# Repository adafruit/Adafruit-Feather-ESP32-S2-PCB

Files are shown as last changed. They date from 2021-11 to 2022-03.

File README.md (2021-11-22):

## Adafruit ESP32-S2 Feather

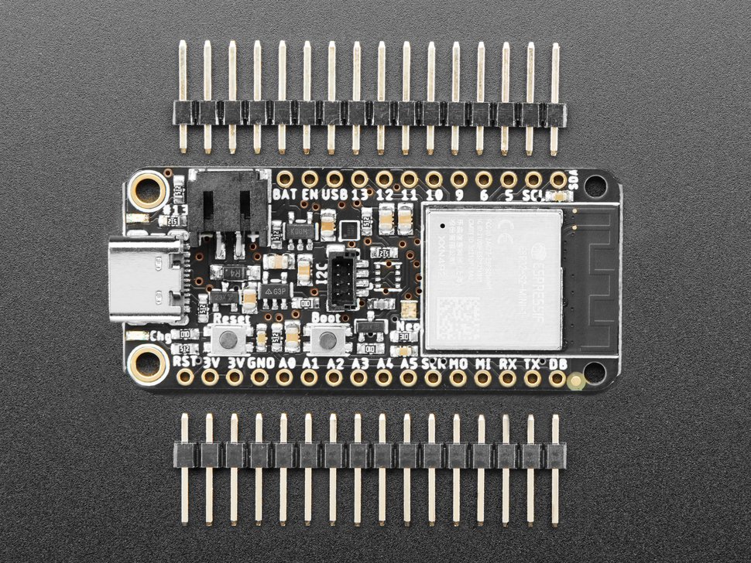
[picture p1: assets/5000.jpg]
<a href="http://www.adafruit.com/products/5000"><br/>
Click here to purchase one from the Adafruit shop</a>

### ESP32-S2 Feather with BME280

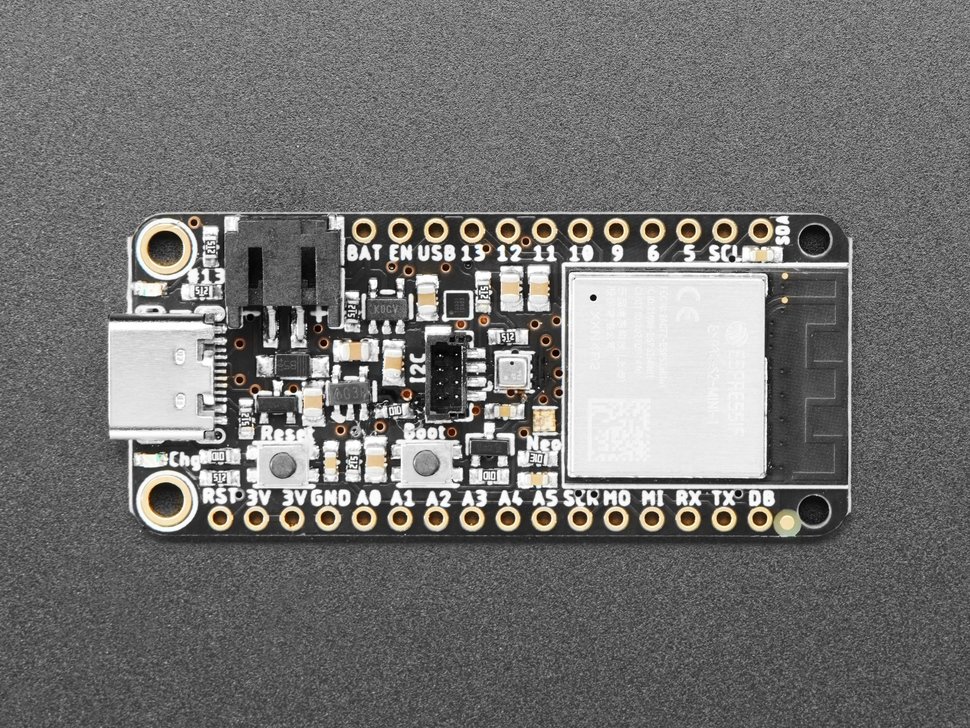
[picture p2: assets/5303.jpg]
<a href="http://www.adafruit.com/products/5303"><br/>
Click here to purchase one from the Adafruit shop</a>

PCB files for the Adafruit ESP32-S2 Feather 

Format is EagleCAD schematic and board layout
* https://www.adafruit.com/product/5000
* https://www.adafruit.com/product/5303

### Description

What's Feather-shaped and has an ESP32-S2 WiFi module? What has a STEMMA QT connector for I2C devices? What has your favorite Espressif WiFi microcontroller and lots of Flash and RAM memory for your next IoT project? What will make your next IoT project flyyyyy?

That's right - it's the new Adafruit ESP32-S2 Feather! With native USB and 4 MB flash + 2 MB of PSRAM, this board is perfect for use with CircuitPython or Arduino with low-cost WiFi. Native USB means it can act like a keyboard or a disk drive. WiFi means its awesome for IoT projects. And Feather means it works with the large community of Feather Wings for expandability.

The ESP32-S2 is a highly-integrated, low-power, 2.4 GHz Wi-Fi System-on-Chip (SoC) solution that now has built-in native USB as well as some other interesting new technologies like Time of Flight distance measurements. With its state-of-the-art power and RF performance, this SoC is an ideal choice for a wide variety of application scenarios relating to the Internet of Things (IoT), wearable electronics, and smart homes.

### License

Adafruit invests time and resources providing this open source design, please support Adafruit and open-source hardware by purchasing products from [Adafruit](https://www.adafruit.com)!

Designed by Limor Fried/Ladyada for Adafruit Industries.

Creative Commons Attribution/Share-Alike, all text above must be included in any redistribution. 
See license.txt for additional details.

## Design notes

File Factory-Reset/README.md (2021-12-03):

# Factory Reset File

This is the factory reset file for the Feather ESP32-S2.

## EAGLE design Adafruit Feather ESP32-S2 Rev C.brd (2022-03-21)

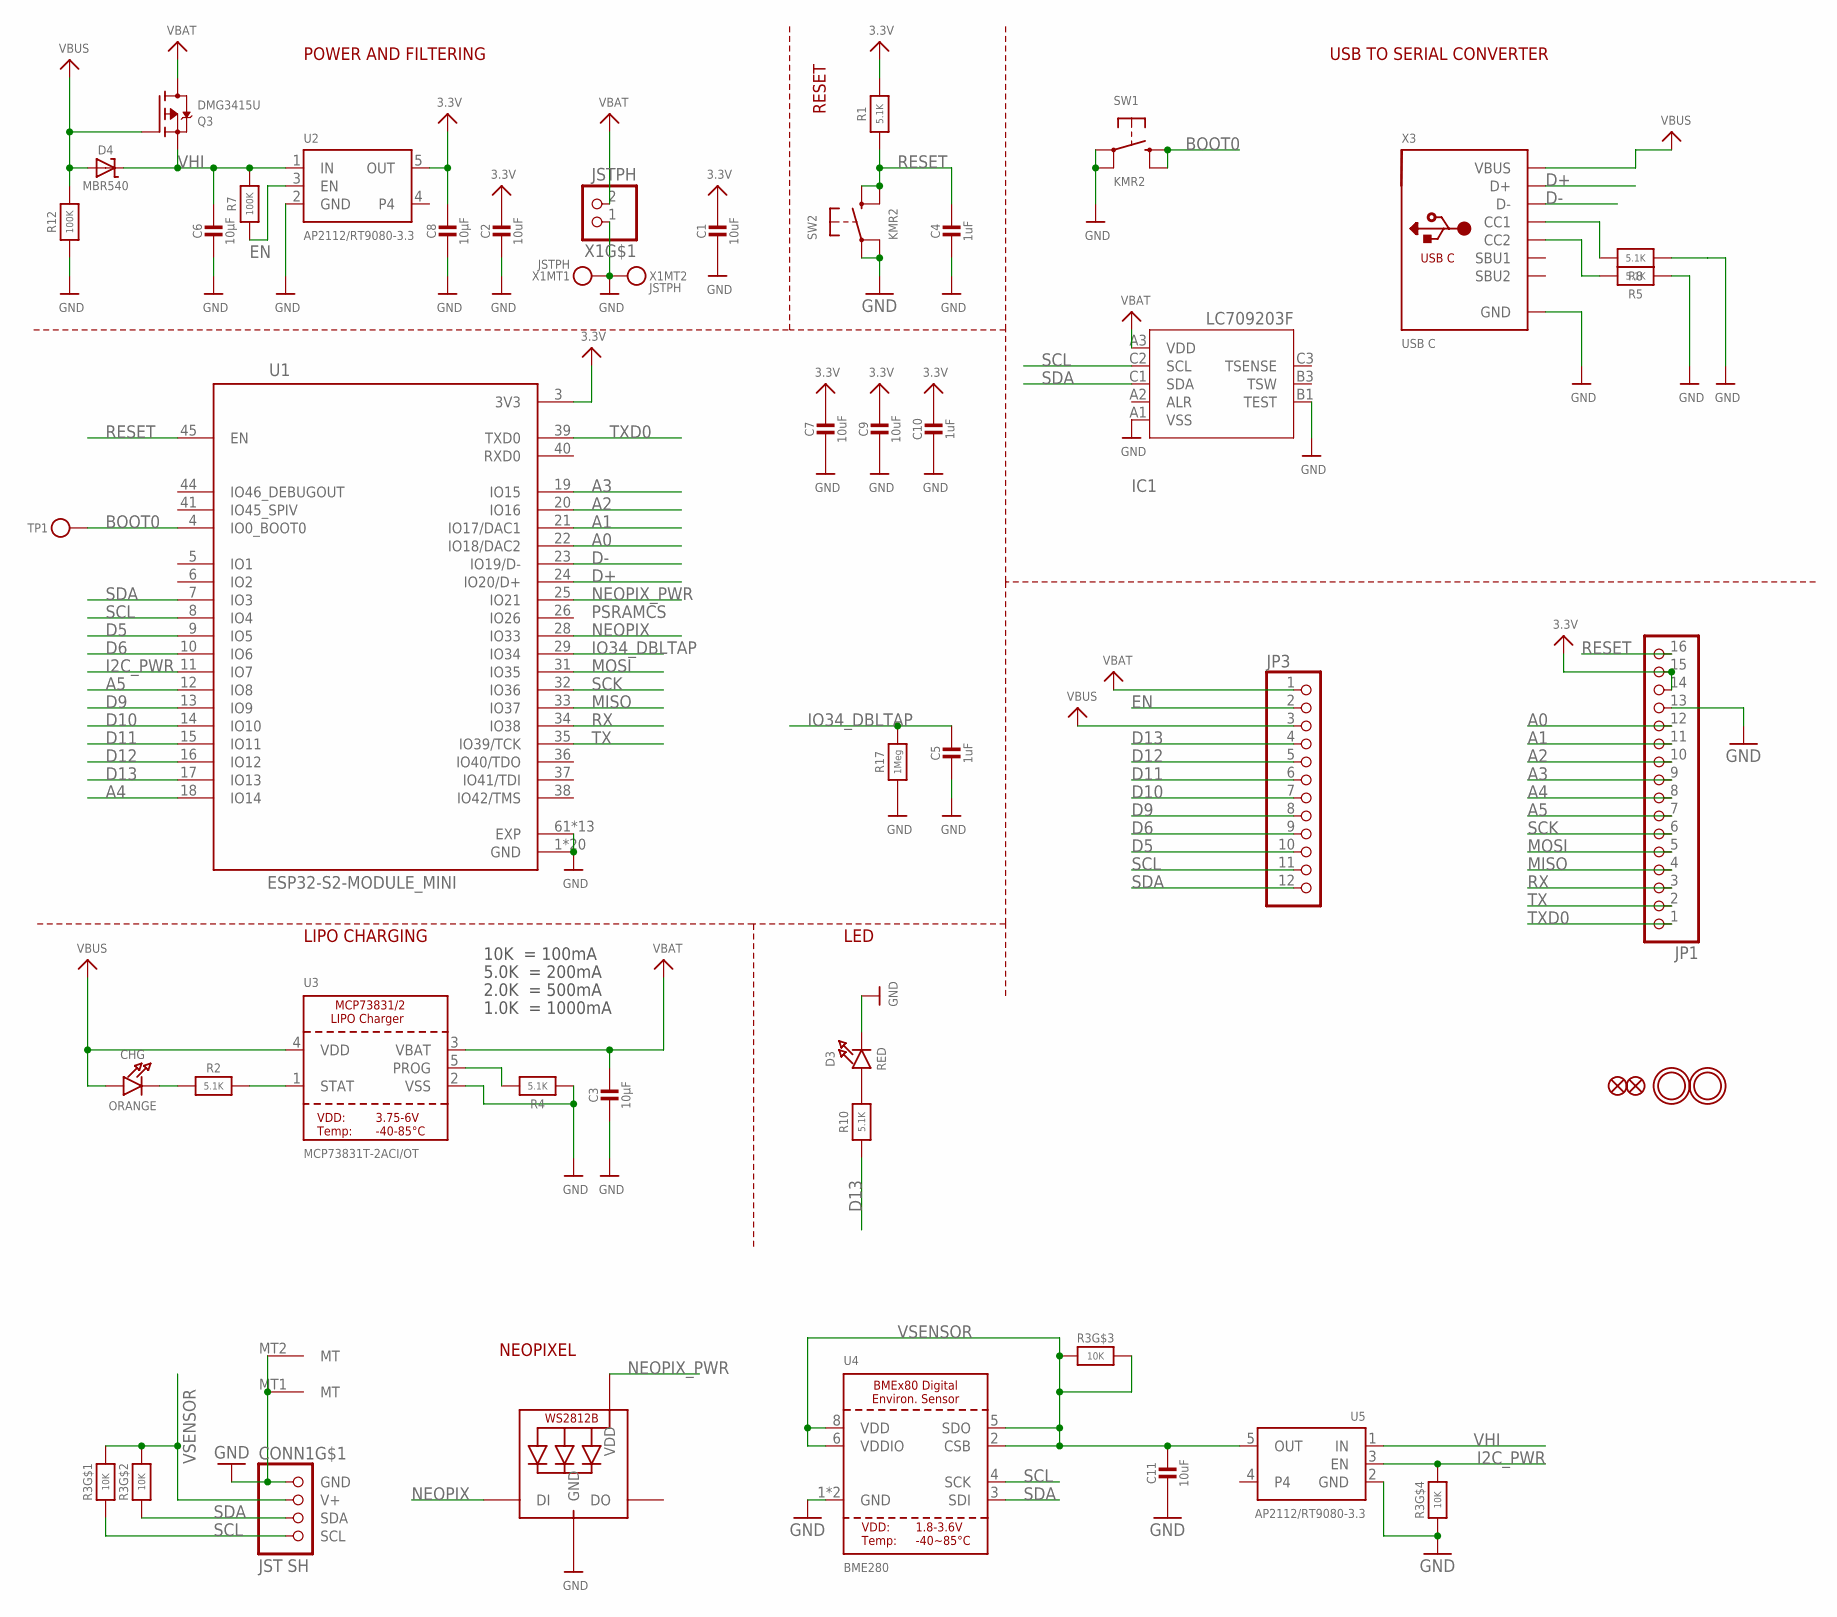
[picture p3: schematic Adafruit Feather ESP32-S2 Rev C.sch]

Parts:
C1, C2, C7, C9: 10uF; 0805-NO
C3, C6, C8: 10µF; 0805-NO
C4, C5, C10: 1uF; 0603-NO
C11: 10uF; _0805MP
CHG: ORANGE; CHIPLED_0603_NOOUTLINE
CONN1: JST SH; JST_SH4_RA
D3: RED; CHIPLED_0603_NOOUTLINE
D4: MBR540; SOD-123
IC1: LC709203F/MH; WLCSP9
JP1: HEADER-1X16ROUND; 1X16_ROUND
JP3: HEADER-1X12; 1X12_ROUND
LED1: WS2812B_SK6805_1515; SK6805_1515
Q3: DMG3415U; SOT23-R
R1, R2, R4, R5, R8, R10: 5.1K; 0603-NO
R3: 10K; RESPACK_4X0603
R7, R12: 100K; 0603-NO
R17: 1Meg; 0603-NO
SW1, SW2: KMR2; BTN_KMR2_4.6X2.8
TP1: TESTPOINTROUND1.5MMNO; TESTPOINT_ROUND_1.5MM_NO
U1: ESP32-S2-MODULE_MINI; QFN60_ESP32-S2-MINI-1_EXP
U2, U5: AP2112/RT9080-3.3; SOT23-5
U3: MCP73831T-2ACI/OT; SOT23-5
U4: BME280
U$31, U$32: MOUNTINGHOLE2.5; MOUNTINGHOLE_2.5_PLATED
U$34, U$35: FIDUCIAL_1MM
X1: JSTPH; JSTPH2_BATT
X3: USB C; USB_C_CUSB31-CFM2AX-01-X

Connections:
3.3V: C1.1, C2.1, C7.1, C8.1, C9.1, C10.1, JP1.14, JP1.15, R1.2, U1.3 (3V3), U2.5 (OUT)
A0: JP1.12, U1.22 (IO18/DAC2)
A1: JP1.11, U1.21 (IO17/DAC1)
A2: JP1.10, U1.20 (IO16)
A3: JP1.9, U1.19 (IO15)
A4: JP1.8, U1.18 (IO14)
A5: JP1.7, U1.12 (IO8)
BOOT0: SW1.B (S), SW1.B' (S1), TP1.P$1, U1.4 (IO0_BOOT0)
D5: JP3.10, U1.9 (IO5)
D6: JP3.9, U1.10 (IO6)
D9: JP3.8, U1.13 (IO9)
D10: JP3.7, U1.14 (IO10)
D11: JP3.6, U1.15 (IO11)
D12: JP3.5, U1.16 (IO12)
D13: JP3.4, R10.1, U1.17 (IO13)
D+: U1.24 (IO20/D+), X3.A6 (D+), X3.B6 (D+)
D-: U1.23 (IO19/D-), X3.A7 (D-), X3.B7 (D-)
EN: JP3.2, R7.1, U2.3 (EN)
GND: C1.2, C2.2, C3.2, C4.2, C5.2, C6.2, C7.2, C8.2, C9.2, C10.2, C11.2, CONN1.1 (GND), CONN1.MT1 (MT), CONN1.MT2 (MT), D3.C, IC1.A1 (VSS), IC1.B1 (TEST), JP1.13, LED1.4 (GND), R3.4 (1), R4.1, R5.1, R8.1, R12.1, R17.1, SW1.A, SW1.A' (P1), SW2.A, SW2.A' (P1), U1.1 (GND), U1.2 (GND), U1.30 (GND), U1.42 (GND), U1.43 (GND), U1.46 (GND), U1.47 (GND), U1.48 (GND), U1.49 (GND), U1.50 (GND), U1.51 (GND), U1.52 (GND), U1.53 (GND), U1.54 (GND), U1.55 (GND), U1.56 (GND), U1.57 (GND), U1.58 (GND), U1.59 (GND), U1.60 (GND), U1.61 (EXP), U1.62 (EXP), U1.63 (EXP), U1.64 (EXP), U1.65 (EXP), U1.66 (EXP), U1.67 (EXP), U1.68 (EXP), U1.69 (EXP), U1.70 (EXP), U1.71 (EXP), U1.72 (EXP), U1.73 (EXP), U2.2 (GND), U3.2 (VSS), U4.1 (GND), U4.7 (GND), U5.2 (GND), X1.1, X1.NC1, X1.NC2, X3.A1B12 (GND), X3.B1A12 (GND)
I2C_PWR: R3.5 (2), U1.11 (IO7), U5.3 (EN)
IO34_DBLTAP: C5.1, R17.2, U1.29 (IO34)
MISO: JP1.4, U1.33 (IO37)
MOSI: JP1.5, U1.31 (IO35)
unnamed: CHG.C, R2.1
unnamed: R2.2, U3.1 (STAT)
unnamed: R4.2, U3.5 (PROG)
unnamed: D3.A, R10.2
unnamed: R8.2, X3.A5 (CC1)
unnamed: R5.2, X3.B5 (CC2)
NEOPIX: LED1.1 (DI), U1.28 (IO33)
NEOPIX_PWR: LED1.2 (VDD), U1.25 (IO21)
RESET: C4.1, JP1.16, R1.1, SW2.B (S), SW2.B' (S1), U1.45 (EN)
RX: JP1.3, U1.34 (IO38)
SCK: JP1.6, U1.32 (IO36)
SCL: CONN1.4 (SCL), IC1.C2 (SCL), JP3.11, R3.1, U1.8 (IO4), U4.4 (SCK)
SDA: CONN1.3 (SDA), IC1.C1 (SDA), JP3.12, R3.2 (1), U1.7 (IO3), U4.3 (SDI)
TX: JP1.2, U1.35 (IO39/TCK)
TXD0: JP1.1, U1.39 (TXD0)
VBAT: C3.1, IC1.A3 (VDD), JP3.1, Q3.3 (D), U3.3 (VBAT), X1.2
VBUS: CHG.A, D4.A, JP3.3, Q3.1 (G), R12.2, U3.4 (VDD), X3.A4B9 (VBUS), X3.B4A9 (VBUS)
VHI: C6.1, D4.C, Q3.2 (S), R7.2, U2.1 (IN), U5.1 (IN)
VSENSOR: C11.1, CONN1.2 (V+), R3.3 (1), R3.6 (2), R3.7 (2), R3.8 (2), U4.2 (CSB), U4.5 (SDO), U4.6 (VDDIO), U4.8 (VDD), U5.5 (OUT)

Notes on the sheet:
POWER AND FILTERING
RESET
10K = 100mA
5.0K = 200mA
2.0K = 500mA
1.0K = 1000mA
USB TO SERIAL CONVERTER
LIPO CHARGING
LED
PSRAMCS
NEOPIXEL

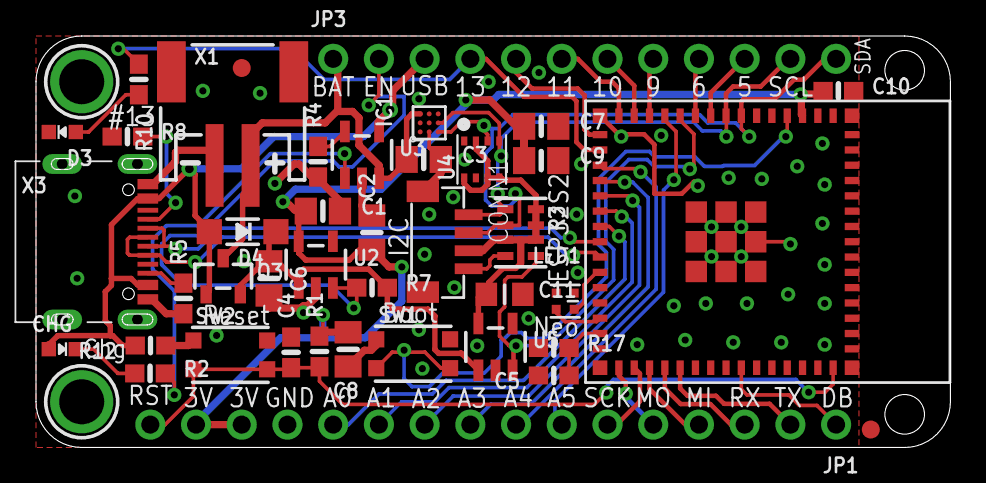
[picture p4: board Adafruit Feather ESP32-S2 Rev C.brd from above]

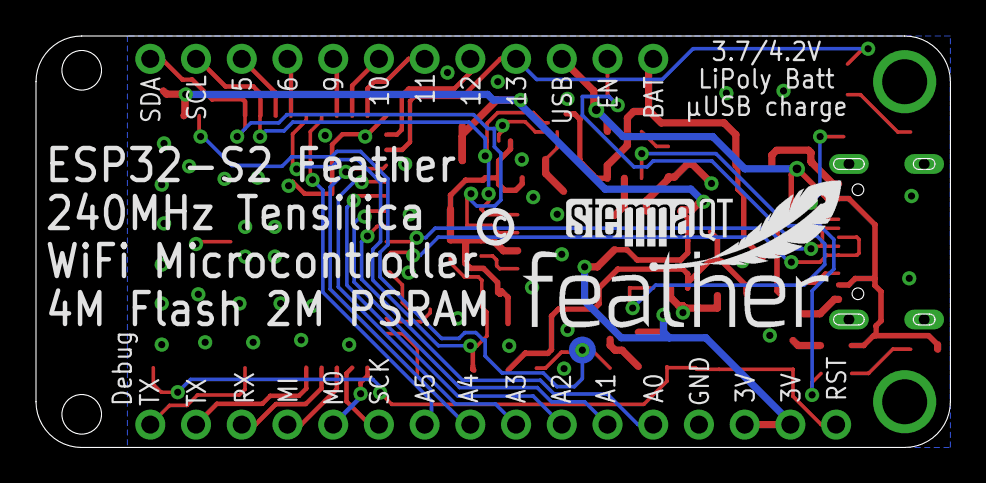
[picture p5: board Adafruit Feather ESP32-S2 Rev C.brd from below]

Board: 2 copper layers, 50.8 x 22.9 mm, 47 parts (4 on the bottom side), 42 nets.

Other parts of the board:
U$14: PCBFEAT-REV-040
U$15: FEATHERLOGO_MED
U$53: STEMMAQT

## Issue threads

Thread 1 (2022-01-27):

I2C powered through pull-ups when I2C_POWER_INVERTED is driven HIGH

dgriswo, 2022-01-27:
When I2C_POWER_INVERTED is driven HIGH, the Q1 MOSFET turns off. This is supposed to turn off external I2C power (VSENSOR).

However, the i2c pull-ups (R3 and R6) are connected to 3.3v not VSENSOR. Since Adafruit STEMMA QT sensors also contain resistors between SDA/SCL and 3v3, the i2c sensors are still powered through the pull-ups.  While the ESP32-S2 is in deep sleep, the VIN pin on the [AHT20 breakout](https://www.adafruit.com/product/4566) is 2.836v. The SDA and SCL lines are both at 3.147v.

Same behavior is seen on the [LTR390 breakout](https://www.adafruit.com/product/4831)

https://forums.adafruit.com/viewtopic.php?f=57&t=187298

ladyada, 2022-01-28:
yes this is going to be fixed in next PCB rev - we'll have a fully separate LDO!

dgriswo, 2022-01-28:
Are you planning to connect the onboard pull-ups to the LDO output?  The mosfet is doing it's job in the current design, just some leakage through the pull-ups.

ladyada, 2022-01-29:
yes the pullups would be also controlled by the LDO. we didn't do that here because we thought folks would want to access the lipo monitor w/o the i2c but turns out... ya cant :D

ladyada, 2022-04-04:
done in rev C

GitHubGoody, 2022-05-31:
@ladyada I ordered this board (without the integrated BME280 since I didn't realize that was an option) on 4/12. How can I tell if its a Rev B or C board?

ladyada, 2022-06-05:
look on the bottom of the PCB for a letter in a circle

Closed 2022-04-04.

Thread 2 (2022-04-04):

Adafruit Feather ESP32-S2 Pinout.pdf : error in Stemma VSENSOR signal sources

mew-cx, 2022-04-04:
On the Stemma connector detail of the PrettyPins diagram, there appears to be an error in the available signal sources for the power pin, see the signals highlighted below:

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

The Stemma power pin is only connected to the  VSENSOR signal; it is not possible to route those other signals, so they should be deleted for clarity.

Sorry for not providing a PR, but I don't have the knowledge or toolchain for generating PrettyPins diagrams.

kattni, 2022-04-11:
Thank you for the suggestion! PrettyPins files have been updated, both here and in the guide.

Closed 2022-04-11.

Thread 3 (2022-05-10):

Com port changes while trying to upload Arduino sketch

muttstang, 2022-05-10:
I purchased the Feather ESP32-S2 with BME680 recently and it worked well for a few hours of uploading and editing code with the Arduino 2.0.3 IDE.  Then it started to throw errors when trying to upload.

It was initially on com12 when I started using it and started switching over to com8 while trying to upload the sketch.  If I try uploading on com8 then I get this error:
`WARNING: ESP32-S2FNR2 chip was placed into download mode using GPIO0.
esptool.py can not exit the download mode over USB. To run the app, reset the chip manually.
To suppress this note, set --after option to 'no_reset'.
Upload error: Failed uploading: uploading error: exit status 1`

if I press reset at this point it switches over to FTHRS2BOOT and com8 goes away in the device manager.

If I try to upload on com12 (when it's available) then I get this:

`Sketch uses 615602 bytes (46%) of program storage space. Maximum is 1310720 bytes.
Global variables use 42216 bytes (12%) of dynamic memory, leaving 285464 bytes for local variables. Maximum is 327680 bytes.
Couldn't find a Board on the selected port. Check that you have the correct port selected.  If it is correct, try pressing the board's reset button after initiating the upload.`

The sketch I'm using throws this error from time to time but it didn't seem to bother it while the board was working

`C:\Users\aerejb\Documents\Arduino\libraries\Adafruit_SSD1327\Adafruit_SSD1327.cpp: In member function 'virtual void Adafruit_SSD1327::display()':
C:\Users\aerejb\Documents\Arduino\libraries\Adafruit_SSD1327\Adafruit_SSD1327.cpp:269:57: warning: narrowing conversion of 'first_row' from 'int16_t' {aka 'short int'} to 'uint8_t' {aka 'unsigned char'} inside { } [-Wnarrowing]
                    SSD1327_SETCOLUMN, row_start, row_end};
                                                         ^
C:\Users\aerejb\Documents\Arduino\libraries\Adafruit_SSD1327\Adafruit_SSD1327.cpp:269:57: warning: narrowing conversion of 'last_row' from 'int16_t' {aka 'short int'} to 'uint8_t' {aka 'unsigned char'} inside { } [-Wnarrowing]
C:\Users\aerejb\Documents\Arduino\libraries\Adafruit_SSD1327\Adafruit_SSD1327.cpp:269:57: warning: narrowing conversion of 'row_start' from 'int16_t' {aka 'short int'} to 'uint8_t' {aka 'unsigned char'} inside { } [-Wnarrowing]
C:\Users\aerejb\Documents\Arduino\libraries\Adafruit_SSD1327\Adafruit_SSD1327.cpp:269:57: warning: narrowing conversion of 'row_end' from 'int16_t' {aka 'short int'} to 'uint8_t' {aka 'unsigned char'} inside { } [-Wnarrowing]
`

I have tried the factory reset https://learn.adafruit.com/adafruit-esp32-s2-feather/factory-reset
I've tried resetting the UF2 file and that gets com12 back but it goes away when I try to upload the sketch.

I don't know if something is wrong with the board, or something changed in my arduino IDE settings but it is quite frustrating.

ladyada, 2022-05-17:
probably your sketch is crashing and killing the USB thread. for help you can post to forums or discord - this repo is for the PCB file

Closed 2022-05-17.

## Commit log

2021-11-22 Renamed files
    [Adafruit Feather ESP32-S2.brd, Adafruit Feather ESP32-S2.sch]
2021-12-23 add i2c scan
2022-03-21 Add rev C board files.
    [Adafruit Feather ESP32-S2 Rev C.brd, Adafruit Feather ESP32-S2 Rev C.sch]
2023-06-21 Updating factory reset files
    Updating factory reset files to check for either LC or MAX battery monitors

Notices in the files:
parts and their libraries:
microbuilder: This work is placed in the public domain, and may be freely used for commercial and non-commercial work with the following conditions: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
